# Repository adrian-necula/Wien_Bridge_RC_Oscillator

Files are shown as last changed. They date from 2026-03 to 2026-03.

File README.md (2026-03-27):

# Wien Bridge RC Oscillator

This repository contains the complete hardware design, TINA-TI simulation, and PCB layout for a tunable Wien Bridge RC Oscillator. The project was developed for the **Fundamental Electronic Circuits 2 (CEF2)** course at ETTI, UNSTPB.

## ⚙️ Technical Specifications
The circuit generates a stable sine wave and features automatic amplitude control using a diode dipole. 
* **Tunable Frequency Range:** 9.5 kHz to 57 kHz.
* **Output Amplitude:** 0.70 V.
* **Output Load:** 19 kΩ.
* **Operating Temperature:** -40°C to 120°C.
* **Amplitude Control:** Automatic, implemented via a diode dipole network.
* **Visual Indicator:** LED power presence indicator.

## 🛠️ Tools & Technologies
* **Simulation:** TINA-TI (Transient and AC Analysis).
* **Schematic Capture:** OrCAD Capture CIS.
* **PCB Design:** OrCAD PCB Editor (Surface-Mount Technology - SMT).

## 📂 Repository Structure
The repository is organized to follow the standard hardware design flow:

* 📁 **`Schematics/`**: Contains the OrCAD source schematic (`.dsn`), the TINA-TI simulation file, and high-resolution images of the final schematic.
* 📁 **`Layout/`**: Contains the OrCAD PCB layout file (`.brd`), the generated manufacturing files (Gerbers/NC Drill), and an image of the routed PCB.
* 📁 **`Simulations/`**: Contains oscilloscope screenshots from TINA-TI verifying the sine wave generation and frequency response.
* 📁 **`Data_Sheets/`**: Official manufacturer datasheets for the critical components used in the design (e.g., op-amps, diodes).
* 🖼️ **`schema_bloc.png`**: The system-level block diagram illustrating the oscillator's functional stages.
* 📄 **`BOM_P1_Necula_Adrian.xls`**: The Bill of Materials detailing the selected components.
* 📄 **`Documentatie.pdf`**: The comprehensive project report, including design equations, thermal considerations, and full layout prints.

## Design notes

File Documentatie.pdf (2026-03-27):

## UNIVERSITATEA NAȚIONALĂ de ȘTIINȚĂ și

## TEHNOLOGIE POLITEHNICA din BUCUREŞTI

## Facultatea de Electronică, Telecomunicaţii şi Tehnologia Informaţiei

## Circuite electronice fundamentale 2 - Proiect

Student: | Necula Adrian-Nicușor
Coordonatori: | Conf. Dr. Ing. Florin Drăghici Ș.l. Dr. Ing. Mihaela Pantazică

### Grupa 433E

### București 2025 – 2026

### 1. Date inițiale de proiectare

- N = 19;
- Frecvența de oscilaţie reglabilă, fosc în intervalul [0,5N ; 3N] kHz, adică [9,5 ; 57] kHz;
- Sarcina la ieșire N, adică RL = 19 kΩ;
- Control automat al amplitudinii de oscilaţie realizat cu dipol cu diode;
- Amplitudinea oscilației la ieșire [20/1,5N] V, adică vosc = 0,70 V;
- Domeniul temperaturilor de funcționare: [-40 ; 120] °C (verificabil prin testare în temperatură);
- Semnalizarea prezenței tensiunilor de alimentare cu diodă de tip LED.

Circuitul va fi proiectat și realizat sub forma unui modul electronic a cărui structură de interconectare va fi concepută în: Tehnologie SMT & PCB.

### 2. Schema bloc a circuitului

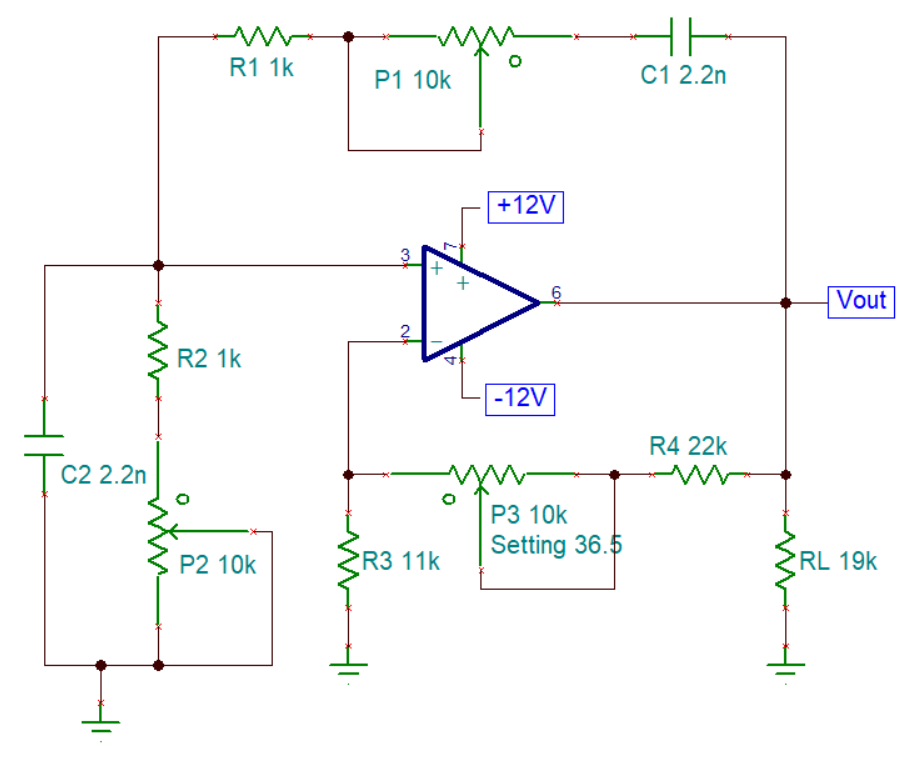
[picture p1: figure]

C1 = C2 = 2.2 nF
R1 =R2 = 1 kΩ
P1 = P2 = [0 ; 10] kΩ

fosc =

1
2πRC

= [9,5 ; 57] kHz

Se pot identifica următoarele blocuri componente:

- Amplificatorul de bază;
- Rețeaua Wien (R1 + P1 = R2 + P2, C1 = C2); Pentru Rețeaua Wien frecvența de oscilație fosc =

1
2πRC

. Valorile pentru componente au fost alese astfel încât să fie acoperită gama de frecvențe indicată indiferent de toleranțele acestora. P1, respectiv P2 sunt potențiometre duble ce permit reglajul simultan al brațelor punții Wien și pentru a avea fosc,min setăm potențiometrele la 66.15 %, iar pentru fosc,max la 2.69 %.
- Rețeaua de reacție negativă formată din R3 și P3 + R4;
- Rezistența de sarcină RL.

### 3. Proiectarea amplificatorului

Următoarea figură prezintă schema finală de implementare a amplificatorului. Acest circuit conține amplificatorul de bază și rețeaua de reacție negativă.

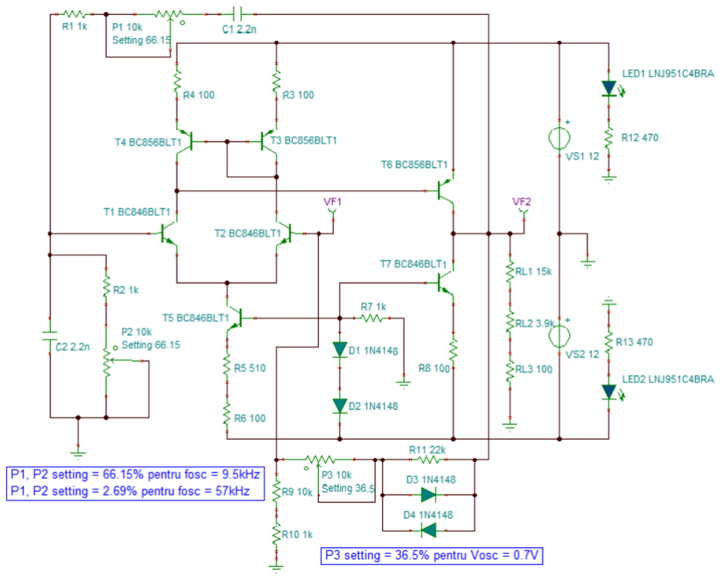
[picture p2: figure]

Amplificatorul este format din următoarele blocuri componente:

1. Etajul diferențial de intrare este realizat de tranzistoarele T1 și T2, ce are rolul de a amplifica diferența de tensiune dintre intrări;
2. Oglinda de curent formată din T3 și T4 are rolul de a menţine un curent egal pe ramurile diferenţialului, cu ajutorul rezistorilor R3 = R4 = 100 Ω;
3. Tranzistoarele T5 și T7, împreună cu diodele D1, D2 și rezistorul R7, formează o sursă de curent constant (Itail) la ieșirea din etajul diferențial;
4. Tranzistorul T6, formează ieșirea oscilatorului, acesta situându-se în clasa A de funcționare.

Rețeaua de reacție negativă, formată din R9, R10, P3 + R11 și diodele D3, respectiv D4, este de topologie Serie-Paralel, pentru a obține Rin → ∞, Rout → 0 și o amplificare de A = 3, specifică Oscilatorului RC cu punte Wien. Potențiometrul P3 are rolul de a regla valoarea amplitudinii la ieșire vosc, iar dipolul cu diode o va stabiliza, astfel asigurând reglajul automat al amplitudinii de oscilație.

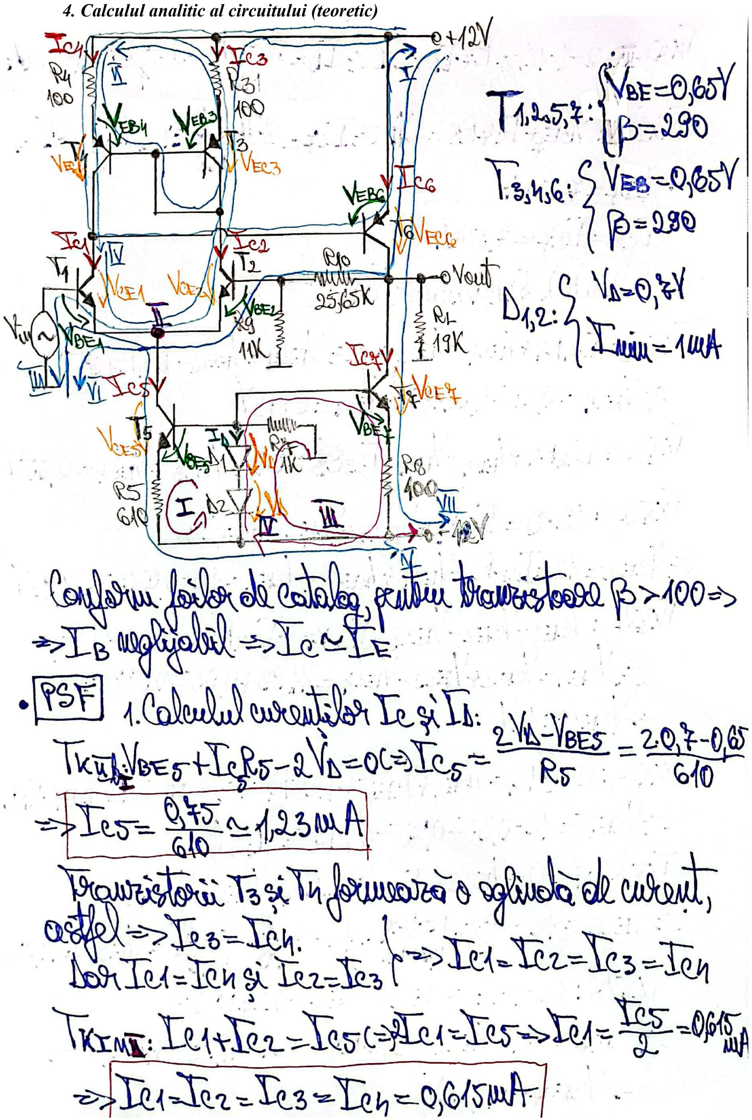
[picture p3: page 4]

### 4. Calculul analitic al circuitului (teoretic)

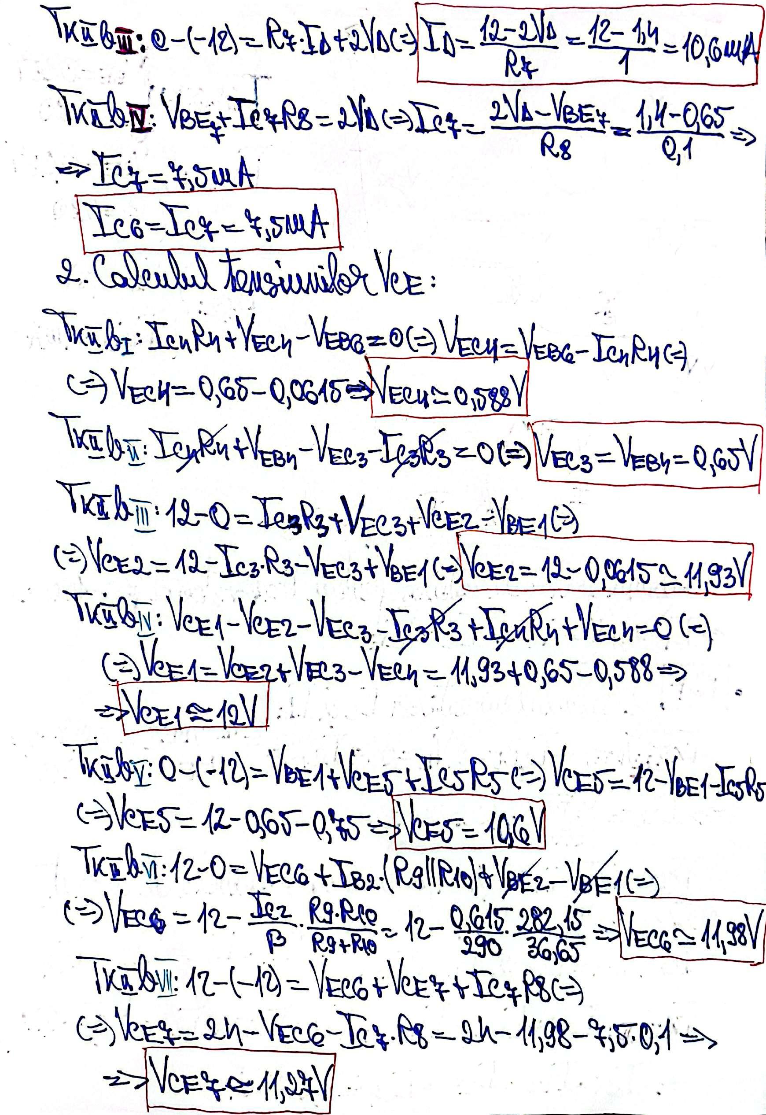
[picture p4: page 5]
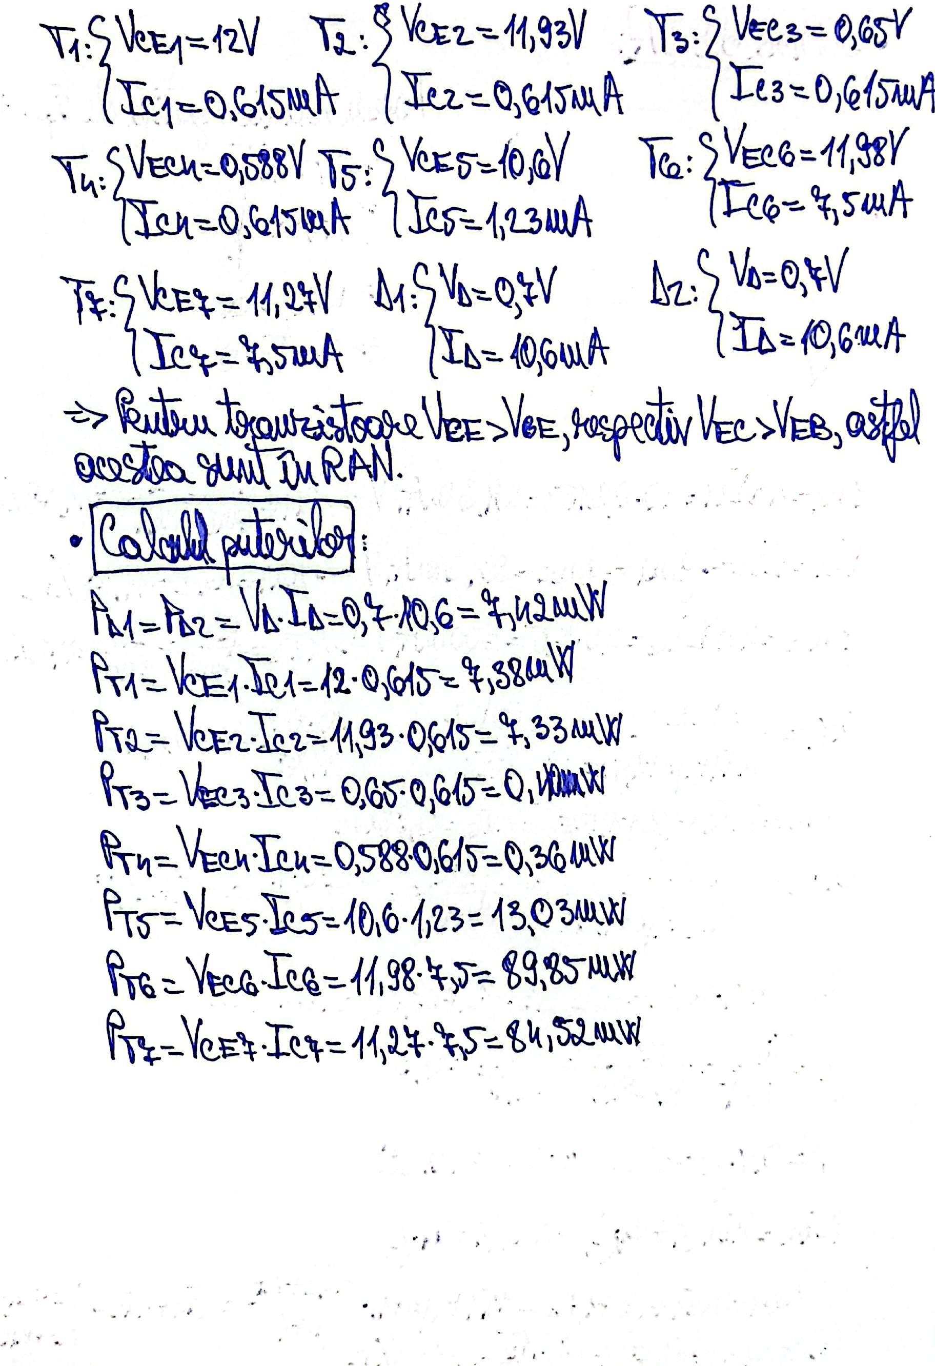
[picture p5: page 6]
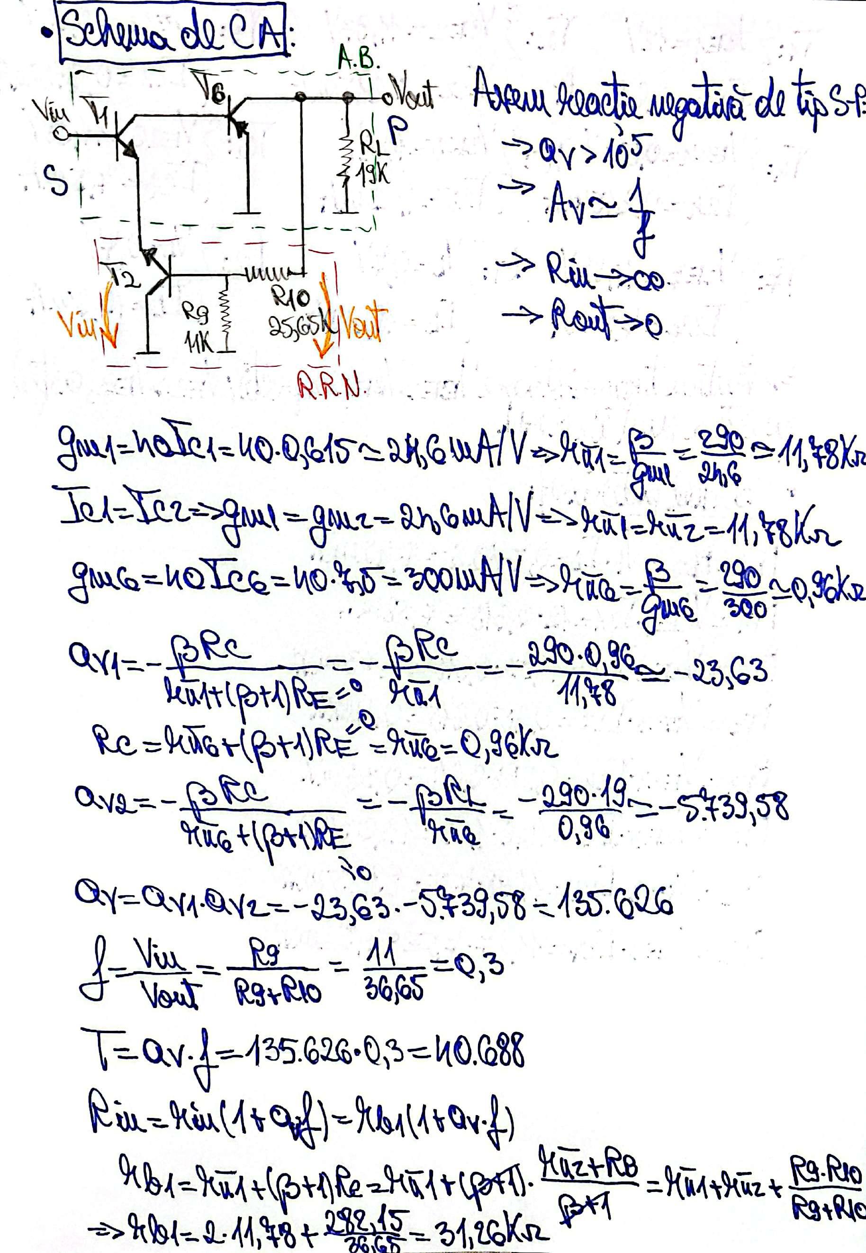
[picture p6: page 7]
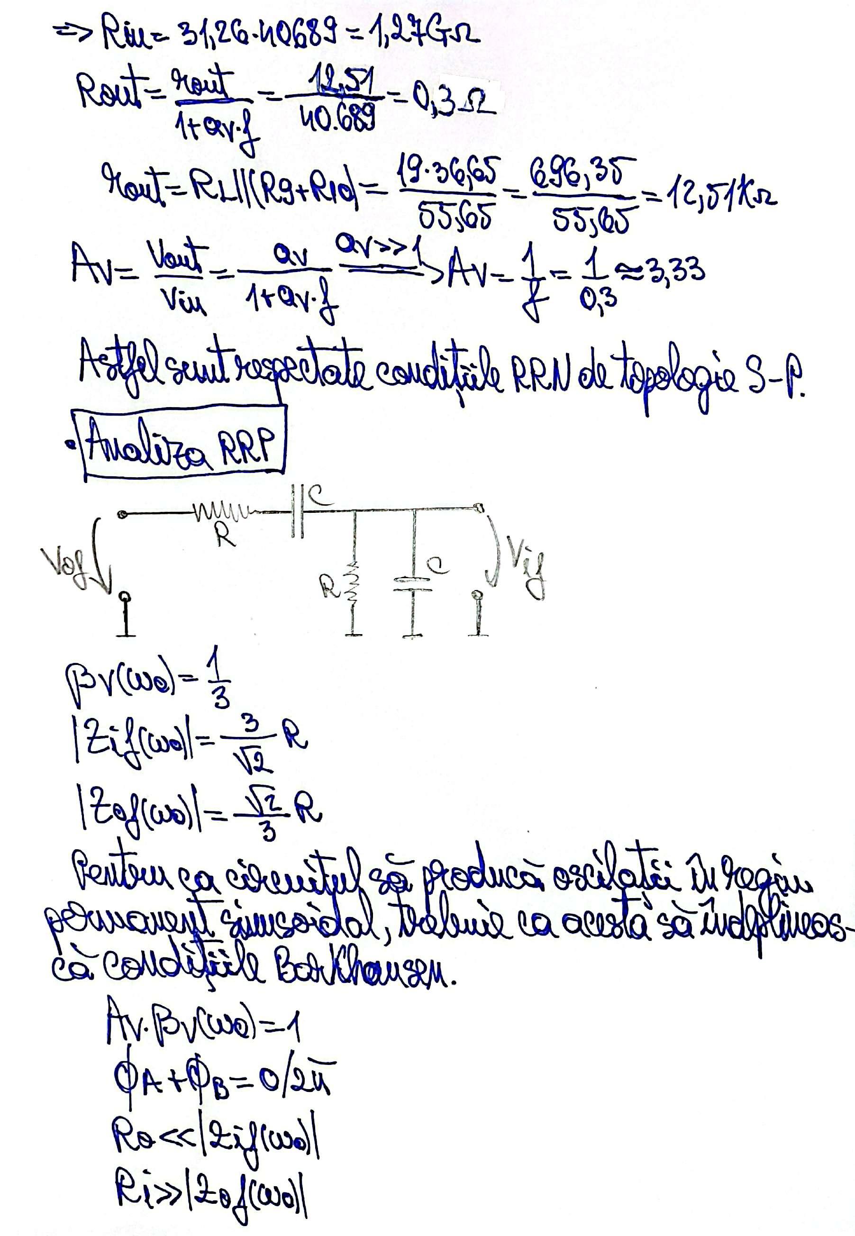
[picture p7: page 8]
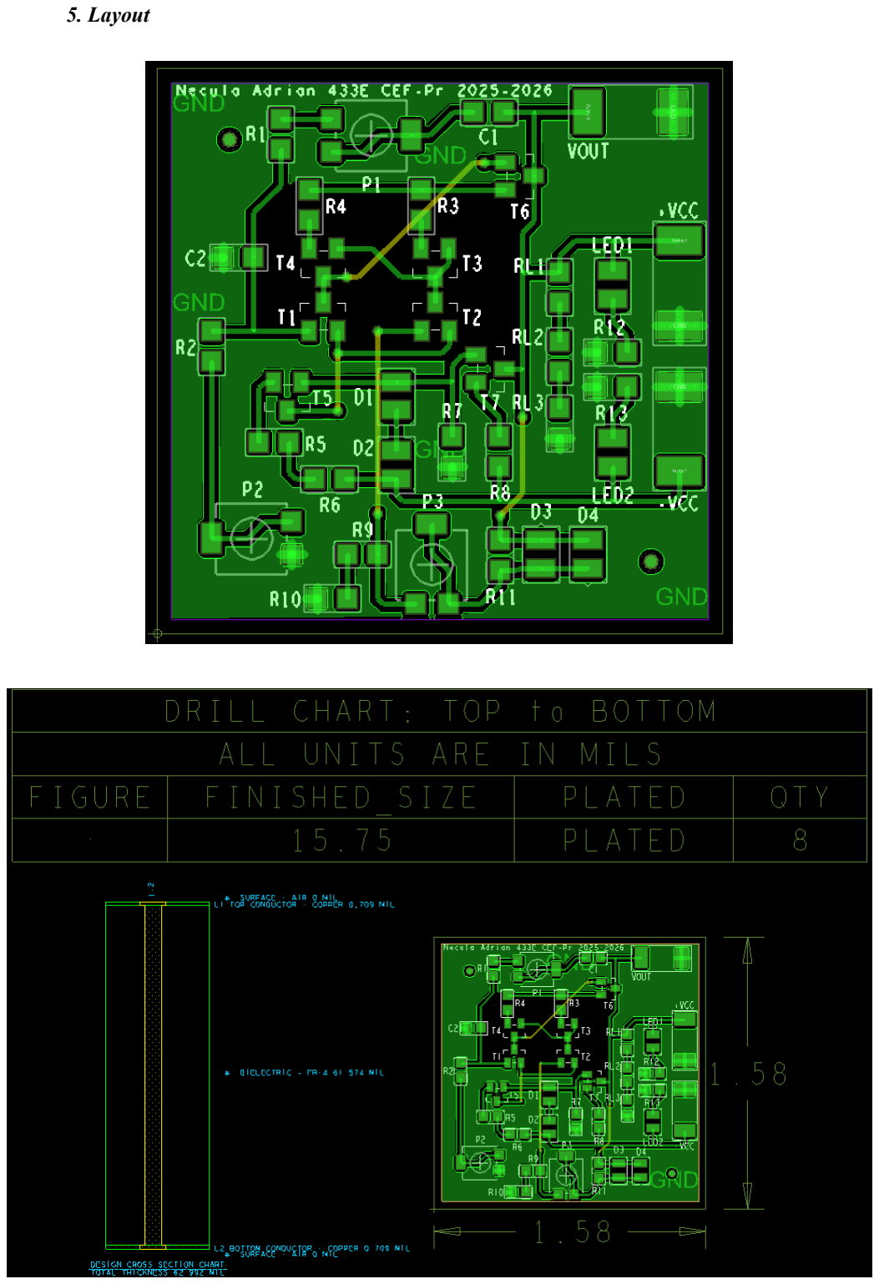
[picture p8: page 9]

### 5. Layout

- Layer electric: TOP

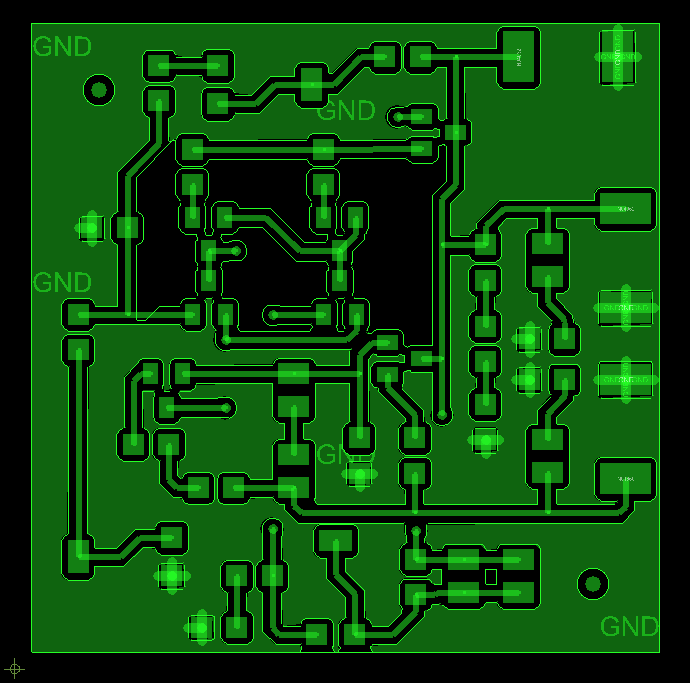
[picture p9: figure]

- Layer electric: BOTTOM

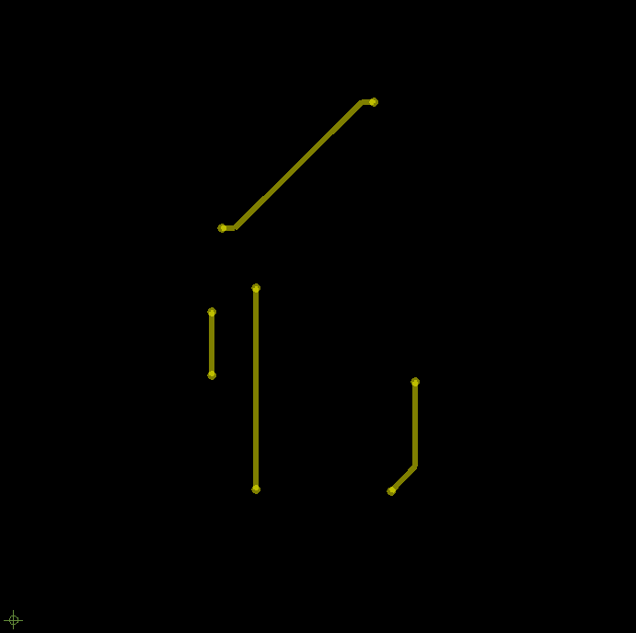
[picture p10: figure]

- Layer neelectric: SMTOP (Solder Mask Top)

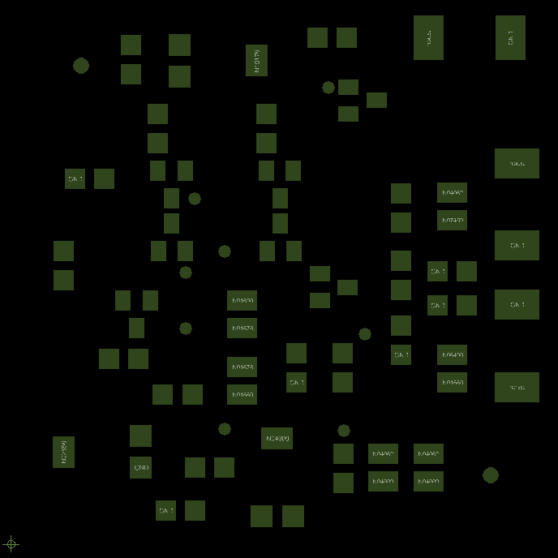
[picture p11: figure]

- Layer neelectric: SMBOT (Solder Mask Bottom)

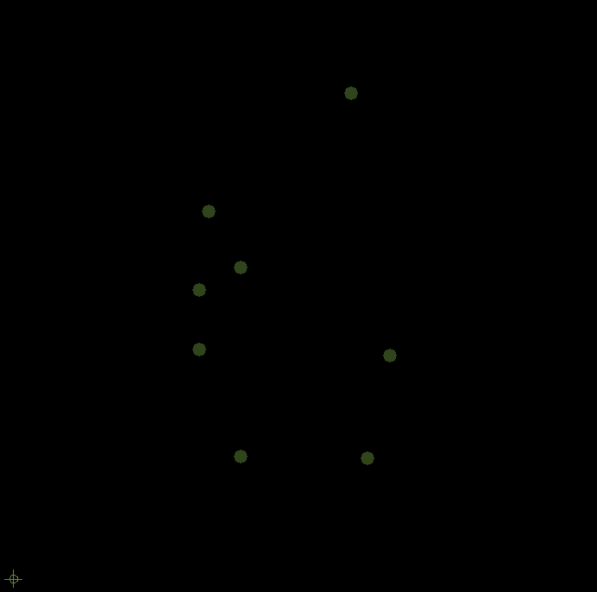
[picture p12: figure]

- Layer neelectric: SSTOP (Silk Screen Top)

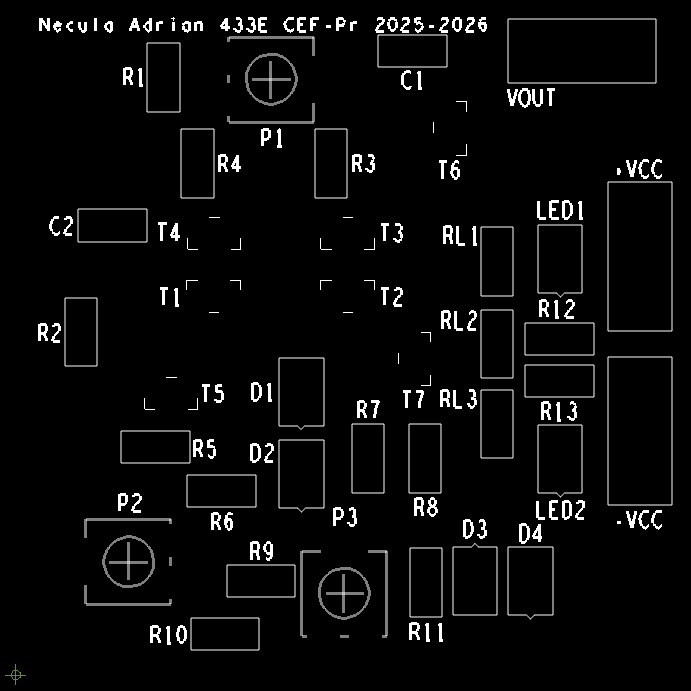
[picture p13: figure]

- Layer neelectric: SPTOP (Solder Paste/Paste Mask Top)

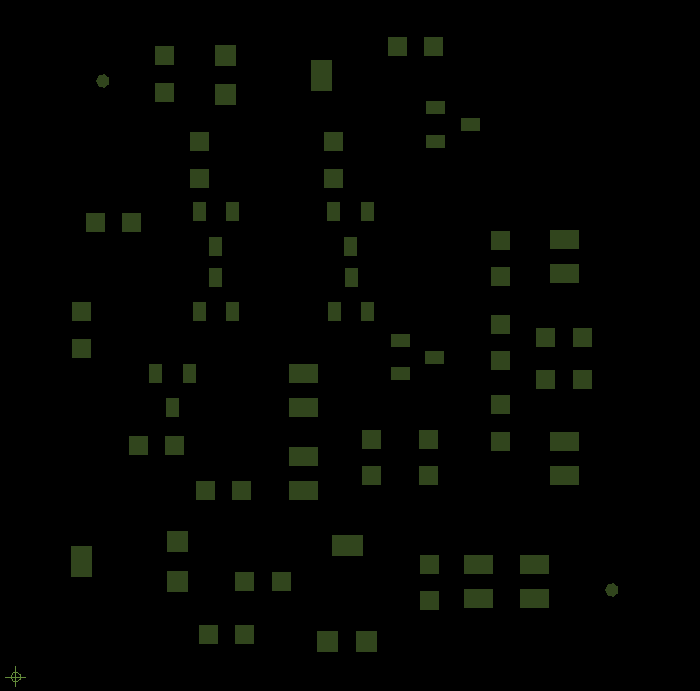
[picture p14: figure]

- Layer neelectric: FAB (Fabrication/Mecanic)

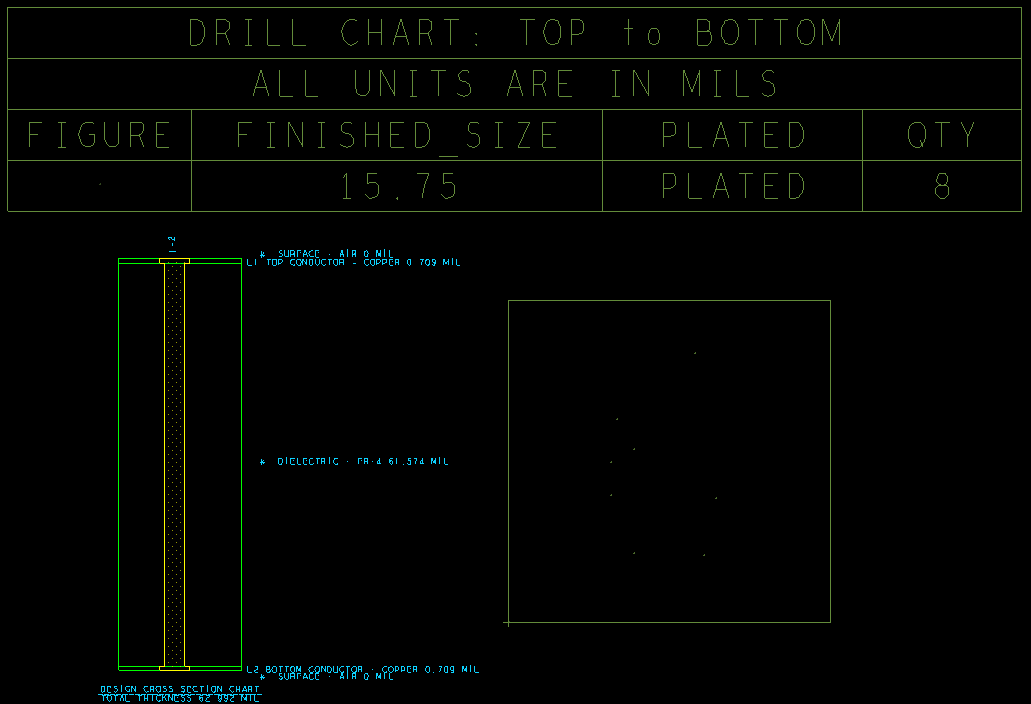
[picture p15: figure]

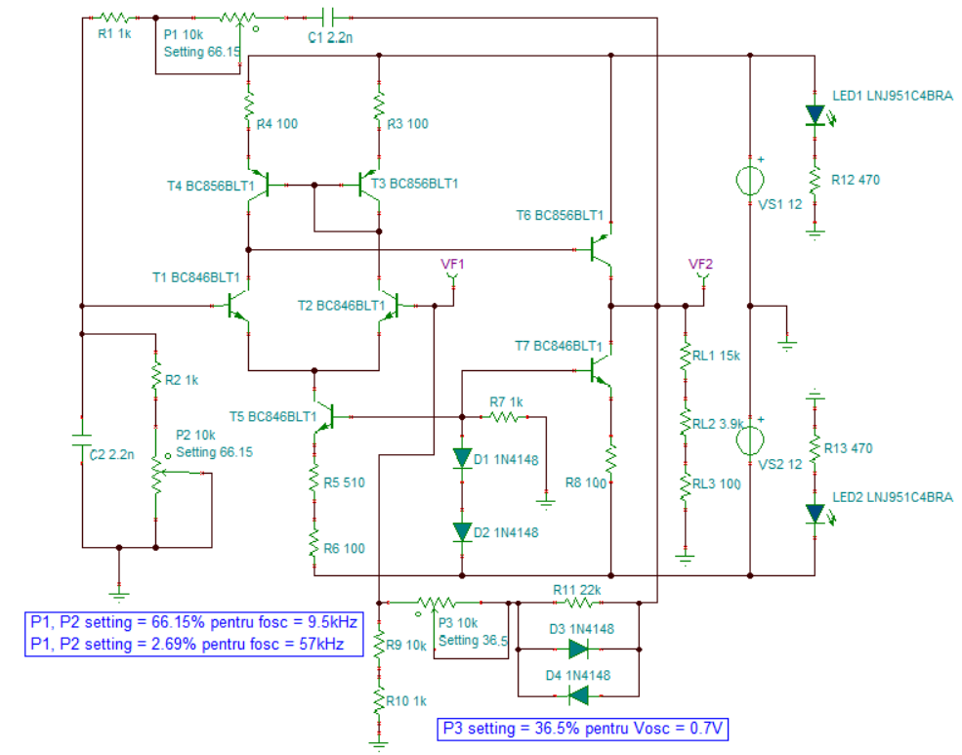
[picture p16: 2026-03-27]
Schematics/schema_finala.png

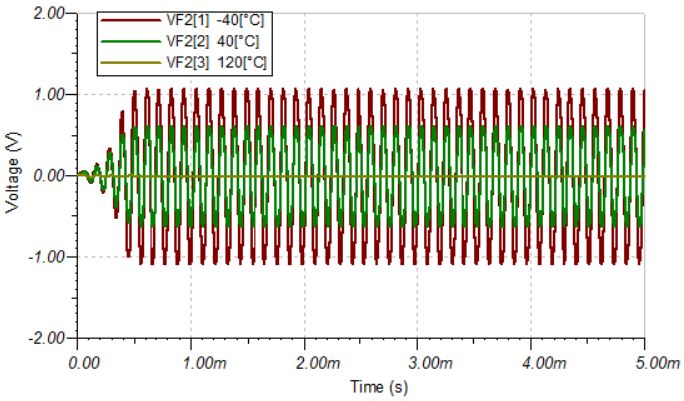
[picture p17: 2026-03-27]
Simulations/variatie_temp_fmin.png

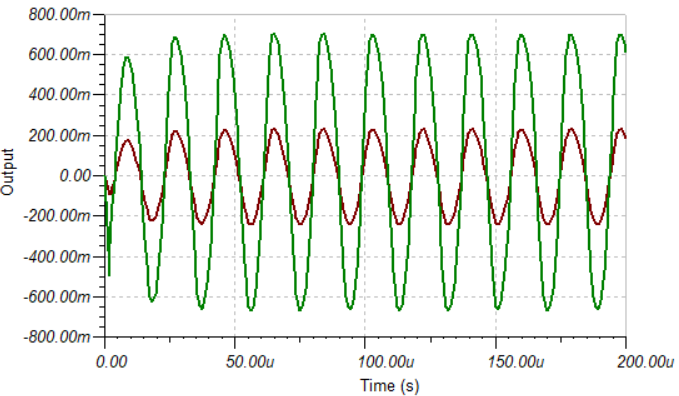
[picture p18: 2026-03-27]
Simulations/fmax.png

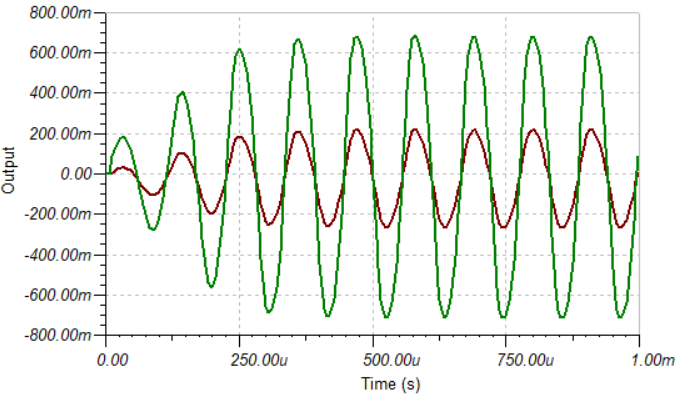
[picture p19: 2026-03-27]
Simulations/fmin.png

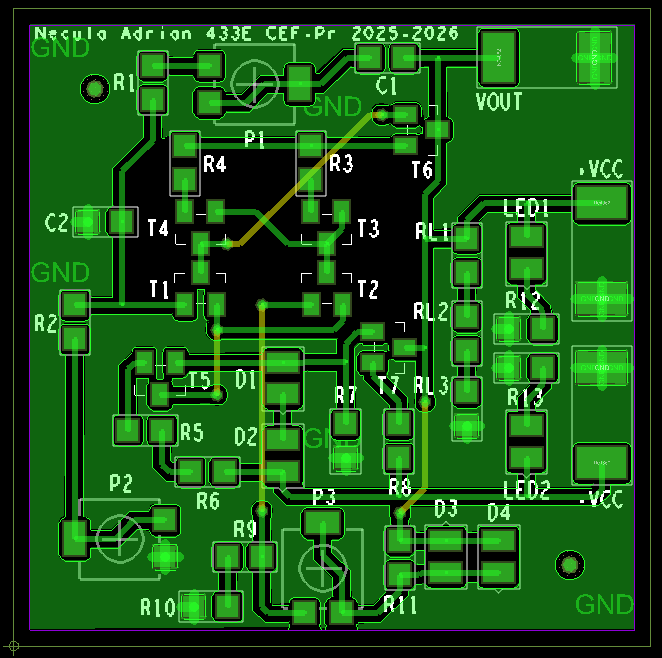
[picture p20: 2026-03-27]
Layout/layout.png

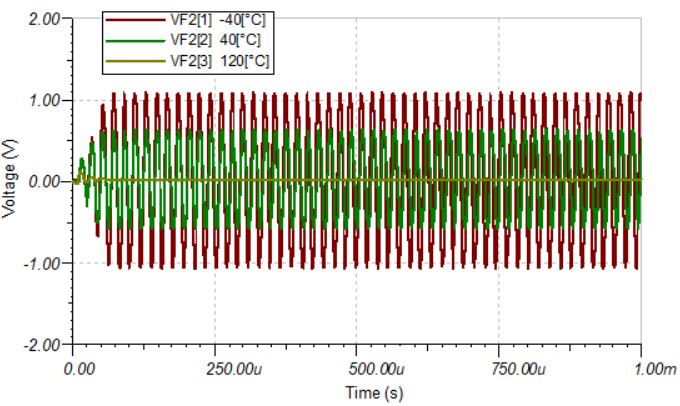
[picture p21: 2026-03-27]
Simulations/variatie_temp_fmax.png

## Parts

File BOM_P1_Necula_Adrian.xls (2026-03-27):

Anexa a1 - Grupa 433E - Tema 1- Oscilator RC cu retea Wien
Nr. Crt. | Nume | Catalog | Cod distrib | Nume prod | Prod | Clasă | Qty fix | Qty final | Qty min | Descriere | Distribuitor | Pret (fara TVA) referinta/buc. TME România | Pret total pe reper (fara TVA) - propus
1 | 0 ohm | (LINK) (http://www.tme.eu/ro/details/smd1206-0r/rezistente-smd-1206/royal-ohm/1206s4j0000t5e/) | 1206S4J0000T5E | 1206S4J0000T5E | SR PASSIVES | rezistor | 0 |  | 0 | Rezistor: thick film; SMD; 1206; 0Ω; 0,25W; ±5%; -55÷125°C | TME România | 0.03841 | 0
2 | 0.47 | (LINK) (http://www.tme.eu/ro/details/smd0805-0r47/rezistente-smd-0805/royal-ohm/0805s8j047kt5e/) | SMD0805-0R47 | 0805S8J047KT5E | ROYAL OHM | rezistor | 20 |  | 0 | Rezistor SMD, chip, 0805, 0.47Ω, ±5%, 0.125W | TME România | 0.01454 | 0.2908
3 | 1 | (LINK) (https://www.tme.eu/ro/details/smd0805-1r/rezistente-smd-0805/royal-ohm/0805s8j010jt5e/) | SMD0805-1R-5% | 0805S8J010JT5E | ROYAL OHM | rezistor | 20 |  | 0 | Rezistor SMD, chip, 0805, 1Ω, ±5%, 0.125W | TME România | 0.01723 | 0.3446
4 | 4.7 | (LINK) (https://www.tme.eu/ro/details/smd0805-4r7/rezistente-smd-0805/royal-ohm/0805s8j047jt5e/) | SMD0805-4R7-5% | 0805S8J047JT5E | ROYAL OHM | rezistor | 10 |  | 0 | Rezistor SMD, chip, 0805, 4.7Ω, ±5%, 0.125W | TME România | 0.01723 | 0.1723
5 | 10 | (LINK) (https://www.tme.eu/ro/details/smd0805-10r/rezistente-smd-0805/royal-ohm/0805s8j0100t5e/) | SMD0805-10R-5% | 0805S8J0100T5E | ROYAL OHM | rezistor | 10 |  | 0 | Rezistor SMD, chip, 0805, 10Ω, ±5%, 0.125W | TME România | 0.01723 | 0.1723
6 | 22 | (LINK) (https://www.tme.eu/ro/details/smd0805-22r-1%25/rezistente-smd-0805/royal-ohm/0805s8f220jt5e/) | SMD0805-22R-1% | 0805S8F220JT5E | ROYAL OHM | rezistor | 20 |  | 0 | Rezistor SMD, chip, 0805, 22Ω, ±1%, 0.125W | TME România | 0.02127 | 0.4254
7 | 33 | (LINK) (https://www.tme.eu/ro/details/smd0805-33r/rezistente-smd-0805/royal-ohm/0805s8j0330t5e/) | SMD0805-33R-5% | 0805S8J0330T5E | ROYAL OHM | rezistor | 20 |  | 0 | Rezistor SMD, chip, 0805, 33Ω, ±5%, 0.125W | TME România | 0.01723 | 0.3446
8 | 51 | (LINK) (http://www.tme.eu/ro/details/rc0805jr-0751r/rezistente-smd-0805/yageo/rc0805jr-0751rl/) | SMD0805-51R-5% | 0805S8J0510T5E | ROYAL OHM | rezistor | 40 |  | 0 | Rezistor SMD, chip, 0805, 51Ω, ±5%, 0.125W | TME România | 0.0261 | 1.044
9 | 68 | (LINK) (http://www.tme.eu/ro/details/smd0805-68r-1%25/rezistente-smd-0805/royal-ohm/0805s8f680jt5e/) | SMD0805-68R-1% | 0805S8F680JT5E | ROYAL OHM | rezistor | 10 |  | 0 | Rezistor SMD, chip, 0805, 68Ω, ±1%, 0.125W | TME România | 0.04662 | 0.4662
10 | 82 | (LINK) (https://www.tme.eu/ro/details/wf08p-82r-5%25/rezistente-smd-0805/walsin/wf08p820jtl/) | SMD0805-82R-5% | WF08P820JTL | WALSIN | rezistor | 20 |  | 0 | Rezistor SMD, chip, 0805, 82Ω, ±5%, 0.125W | TME România | 0.0172 | 0.344
11 | 100 | (LINK) (https://www.tme.eu/ro/details/smd0805-100r/rezistente-smd-0805/royal-ohm/0805s8j0101t5e/) | SMD0805-100R-5% | 0805S8J0101T5E | ROYAL OHM | rezistor | 60 |  | 5 | Rezistor SMD, chip, 0805, 100Ω, ±5%, 0.125W | TME România | 0.01723 | 1.0338
12 | 150 | (LINK) (https://www.tme.eu/ro/details/smd0805-150r/rezistente-smd-0805/royal-ohm/0805s8j0151t5e/) | SMD0805-150R-5% | 0805S8F1500T5E | ROYAL OHM | rezistor | 30 |  | 0 | Rezistor SMD, chip, 0805, 150Ω, ±5%, 0.125W | TME România | 0.01723 | 0.5169
13 | 220 | (LINK) (http://www.tme.eu/ro/details/smd0805-220r-1%25/rezistente-smd-0805/royal-ohm/0805s8f2200t5e/) | SMD0805-220R-5% | 0805S8J0221T5E | ROYAL OHM | rezistor | 30 |  | 0 | Rezistor SMD, chip, 0805, 220Ω, ±5%, 0.125W | TME România | 0.02127 | 0.6381
14 | 330 | (LINK) (https://www.tme.eu/ro/details/smd0805-330r/rezistente-smd-0805/royal-ohm/0805s8j0331t5e/) | SMD0805-330R-5% | 0805S8J0331T5E | ROYAL OHM | rezistor | 30 |  | 0 | Rezistor SMD, chip, 0805, 330Ω, ±5%, 0.125W | TME România | 0.01723 | 0.5169
15 | 470 | (LINK) (https://www.tme.eu/ro/details/smd0805-470r/rezistente-smd-0805/royal-ohm/0805s8j0471t5e/) | SMD0805-470R-5% | 0805S8J0471T5E | ROYAL OHM | rezistor | 30 |  | 2 | Rezistor SMD, chip, 0805, 470Ω, ±5%, 0.125W | TME România | 0.01723 | 0.5169
16 | 510 | (LINK) (https://www.tme.eu/ro/details/smd0805-510r/rezistente-smd-0805/royal-ohm/0805s8j0511t5e/) | SMD0805-510R-5% | 0805S8J0511T5E | ROYAL OHM | rezistor | 30 |  | 1 | Rezistor SMD, chip, 0805, 510Ω, ±5%, 0.125W | TME România | 0.01723 | 0.5169
17 | 680 | (LINK) (https://www.tme.eu/ro/details/smd0805-680r/rezistente-smd-0805/royal-ohm/0805s8j0681t5e/) | SMD0805-680R-5% | 0805S8J0681T5E | ROYAL OHM | rezistor | 30 |  | 0 | Rezistor SMD, chip, 0805, 680Ω, ±5%, 0.125W | TME România | 0.01723 | 0.5169
18 | 820 | (LINK) (https://www.tme.eu/ro/details/smd0805-820r/rezistente-smd-0805/royal-ohm/0805s8j0821t5e/) | SMD0805-820R-5% | 0805S8J0821T5E | ROYAL OHM | rezistor | 30 |  | 0 | Rezistor SMD, chip, 0805, 820Ω, ±5%, 0.125W | TME România | 0.01723 | 0.5169
19 | 910 | (LINK) (https://www.tme.eu/ro/details/rc0805jr-07910r/rezistente-smd-0805/yageo/rc0805jr-07910rl/) | SMD0805-910R-5% | RC0805JR-07910RL | YAGEO | rezistor | 40 |  | 0 | Rezistor SMD, chip, 0805, 910Ω, ±5%, 0.125W | TME România | 0.0261 | 1.044
20 | 1k | (LINK) (https://www.tme.eu/ro/details/smd0805-1k/rezistente-smd-0805/royal-ohm/0805s8j0102t5e/) | SMD0805-1K-5% | 0805S8J0102T5E | ROYAL OHM | rezistor | 100 |  | 4 | Rezistor SMD, chip, 0805, 1kΩ, ±5%, 0.125W | TME România | 0.01723 | 1.723
21 | 1.5k | (LINK) (https://www.tme.eu/ro/details/wf08p-1k5-5%25/rezistente-smd-0805/walsin/wf08p152jtl/) | SMD0805-1K5-5% | WF08P152JTL | WALSIN | rezistor | 40 |  | 0 | Rezistor SMD, chip, 0805, 1.5kΩ, ±5%, 0.125W | TME România | 0.0172 | 0.688
22 | 1.8k | (LINK) (https://www.tme.eu/ro/details/smd0805-1k8/rezistente-smd-0805/royal-ohm/0805s8j0182t5e/) | SMD0805-1K8-5% | 0805S8J0182T5E | ROYAL OHM | rezistor | 30 |  | 0 | Rezistor SMD, chip, 0805, 1.8kΩ, ±5%, 0.125W | TME România | 0.01723 | 0.5169
23 | 2k | (LINK) (https://www.tme.eu/ro/details/smd0805-2k/rezistente-smd-0805/royal-ohm/0805s8j0202t5e/) | SMD0805-2K-5% | 0805S8J0202T5E | ROYAL OHM | rezistor | 80 |  | 0 | Rezistor SMD, chip, 0805, 2kΩ, ±5%, 0.125W | TME România | 0.01723 | 1.3784
24 | 2.2k | (LINK) (https://www.tme.eu/ro/details/smd0805-2k2/rezistente-smd-0805/royal-ohm/0805s8j0222t5e/) | SMD0805-2K2-5% | 0805S8J0222T5E | ROYAL OHM | rezistor | 30 |  | 0 | Rezistor SMD, chip, 0805, 2.2kΩ, ±5%, 0.125W | TME România | 0.01723 | 0.5169
25 | 2.7k | (LINK) (https://www.tme.eu/ro/details/smd0805-2k7/rezistente-smd-0805/royal-ohm/0805s8j0272t5e/) | SMD0805-2K7-5% | 0805S8F2701T5E | ROYAL OHM | rezistor | 30 |  | 0 | Rezistor SMD, chip, 0805, 2.7kΩ, ±5%, 0.125W | TME România | 0.01723 | 0.5169
26 | 3.3k | (LINK) (https://www.tme.eu/ro/details/smd0805-3k3/rezistente-smd-0805/royal-ohm/0805s8j0332t5e/) | SMD0805-3K3-5% | 0805S8J0332T5E | ROYAL OHM | rezistor | 30 |  | 0 | Rezistor SMD, chip, 0805, 3.3kΩ, ±5%, 0.125W | TME România | 0.01723 | 0.5169
27 | 3.9k | (LINK) (https://www.tme.eu/ro/details/smd0805-3k9/rezistente-smd-0805/royal-ohm/0805s8j0392t5e/) | SMD0805-3K9-5% | 0805S8J0392T5E | ROYAL OHM | rezistor | 20 |  | 1 | Rezistor SMD, chip, 0805, 3.9kΩ, ±5%, 0.125W | TME România | 0.01723 | 0.3446
28 | 4.7k | (LINK) (https://www.tme.eu/ro/details/smd0805-4k7/rezistente-smd-0805/royal-ohm/0805s8j0472t5e/) | SMD0805-4K7-5% | 0805S8J0472T5E | ROYAL OHM | rezistor | 30 |  | 0 | Rezistor SMD, chip, 0805, 4.7kΩ, ±5%, 0.125W | TME România | 0.01723 | 0.5169
29 | 5.6k | (LINK) (https://www.tme.eu/ro/details/smd0805-5k6/rezistente-smd-0805/royal-ohm/0805s8j0562t5e/) | SMD0805-5K6-5% | 0805S8J0562T5E | ROYAL OHM | rezistor | 60 |  | 0 | Rezistor SMD, chip, 0805, 5.6kΩ, ±5%, 0.125W | TME România | 0.01723 | 1.0338
30 | 6.8k | (LINK) (https://www.tme.eu/ro/details/rc0805jr-076k8/rezistente-smd-0805/yageo/rc0805jr-076k8l/) | SMD0805-6K8-5% | RC0805JR-076K8L | YAGEO | rezistor | 20 |  | 0 | Rezistor SMD, chip, 0805, 6.8kΩ, ±5%, 0.125W | TME România | 0.0261 | 0.522
31 | 8.2k | (LINK) (https://www.tme.eu/ro/details/smd0805-8k2/rezistente-smd/royalohm/0805s8j0822t5e/) | SMD0805-8K2-5% | 0805S8J0822T5E | ROYAL OHM | rezistor | 30 |  | 0 | Rezistor SMD, chip, 0805, 8.2kΩ, ±5%, 0.125W | TME România | 0.01723 | 0.5169
32 | 9.1k | (LINK) (https://www.tme.eu/ro/details/smd0805-9k1/rezistente-smd-0805/royal-ohm/0805s8j0912t5e/) | SMD0805-9K1-5% | 0805S8J0912T5E | ROYAL OHM | rezistor | 20 |  | 0 | Rezistor SMD, chip, 0805, 9.1kΩ, ±5%, 0.125W | TME România | 0.01723 | 0.3446
33 | 10k | (LINK) (https://www.tme.eu/ro/details/smd0805-10k/rezistente-smd-0805/royal-ohm/0805s8j0103t5e/) | SMD0805-10K-5% | 0805S8J0103T5E | ROYAL OHM | rezistor | 100 |  | 1 | Rezistor SMD, chip, 0805, 10kΩ, ±5%, 0.125W | TME România | 0.01723 | 1.723
34 | 15k | (LINK) (https://www.tme.eu/ro/details/smd0805-15k/rezistente-smd-0805/royal-ohm/0805s8j0153t5e/) | SMD0805-15K-5% | 0805S8J0153T5E | ROYAL OHM | rezistor | 30 |  | 1 | Rezistor SMD, chip, 0805, 15kΩ, ±5%, 0.125W | TME România | 0.01723 | 0.5169
35 | 22k | (LINK) (https://www.tme.eu/ro/details/smd0805-22k/rezistente-smd-0805/royal-ohm/0805s8j0223t5e/) | SMD0805-22K-5% | 0805S8J0223T5E | ROYAL OHM | rezistor | 30 |  | 1 | Rezistor SMD, chip, 0805, 22kΩ, ±5%, 0.125W | TME România | 0.01723 | 0.5169
36 | 47k | (LINK) (http://www.tme.eu/ro/details/smd0805-47k/rezistente-smd-0805/royal-ohm/0805s8j0473t5e/) | SMD0805-47K-5% | 0805S8J0473T5E | ROYAL OHM | rezistor | 40 |  | 0 | Rezistor: thick film; SMD; 0805; 47kΩ; 0,125W; ±5%; -55÷125°C | TME România | 0.01723 | 0.6892
37 | 68k | (LINK) (https://www.tme.eu/ro/details/smd0805-68k/rezistente-smd-0805/royal-ohm/0805s8j0683t5e/) | SMD0805-68K-5% | 0805S8J0683T5E | ROYAL OHM | rezistor | 20 |  | 0 | Rezistor SMD, chip, 0805, 68kΩ, ±5%, 0.125W | TME România | 0.01723 | 0.3446
38 | 100k | (LINK) (https://www.tme.eu/ro/details/smd0805-100k/rezistente-smd-0805/royal-ohm/0805s8j0104t5e/) | SMD0805-100K-5% | 0805S8J0104T5E | ROYAL OHM | rezistor | 100 |  | 0 | Rezistor SMD, chip, 0805, 100kΩ, ±5%, 0.125W | TME România | 0.01723 | 1.723
39 | 150k | (LINK) (http://www.tme.eu/ro/details/smd0805-150k/rezistente-smd-0805/royal-ohm/0805s8j0154t5e/) | SMD0805-150K-5% | 0805S8J0154T5E | ROYAL OHM | rezistor | 30 |  | 0 | Rezistor SMD, chip, 0805, 150kΩ, ±5%, 0.125W | TME România | 0.01723 | 0.5169
40 | 180k | (LINK) (http://www.tme.eu/ro/details/smd0805-180k/rezistente-smd-0805/royal-ohm/0805s8j0184t5e/) | SMD0805-180K-5% | 0805S8J0184T5E | ROYAL OHM | rezistor | 30 |  | 0 | Rezistor SMD, chip, 0805, 180kΩ, ±5%, 0.125W | TME România | 0.01723 | 0.5169
41 | 220k | (LINK) (https://www.tme.eu/ro/details/smd0805-220k/rezistente-smd-0805/royal-ohm/0805s8j0224t5e/) | SMD0805-220K-5% | 0805S8J0224T5E | ROYAL OHM | rezistor | 30 |  | 0 | Rezistor SMD, chip, 0805, 220kΩ, ±5%, 0.125W | TME România | 0.01723 | 0.5169
42 | 330k | (LINK) (https://www.tme.eu/ro/details/smd0805-330k/rezistente-smd-0805/royal-ohm/0805s8j0334t5e/) | SMD0805-330K-5% | 0805S8J0334T5E | ROYAL OHM | rezistor | 30 |  | 0 | Rezistor SMD, chip, 0805, 330kΩ, ±5%, 0.125W | TME România | 0.01723 | 0.5169
43 | 390k | (LINK) (https://www.tme.eu/ro/details/smd0805-390k/rezistente-smd-0805/royal-ohm/0805s8j0394t5e/) | SMD0805-390K-5% | 0805S8J0394T5E | ROYAL OHM | rezistor | 30 |  | 0 | Rezistor SMD, chip, 0805, 390kΩ, ±5%, 0.125W | TME România | 0.01723 | 0.5169
44 | 510k | (LINK) (https://www.tme.eu/ro/details/smd0805-510k/rezistente-smd-0805/royal-ohm/0805s8j0514t5e/) | SMD0805-510K-5% | 0805S8J0514T5E | ROYAL OHM | rezistor | 30 |  | 0 | Rezistor SMD, chip, 0805, 510kΩ, ±5%, 0.125W | TME România | 0.01723 | 0.5169
45 | 1M | (LINK) (https://www.tme.eu/ro/details/crcw08051m00jntabc/rezistente-smd-0805/vishay/) | SMD0805-1M-5% | CRCW08051M00JNTABC | VISHAY | rezistor | 30 |  | 0 | Rezistor SMD, chip, 0805, 1MΩ, ±5%, 0.125W | TME România | 0.01151 | 0.3453
46 | 2M | (LINK) (http://www.tme.eu/ro/details/smd0805-2m/rezistente-smd-0805/royal-ohm/0805waj-2m-t5e/) | SMD0805-2M7 5% | 0805WAJ 2M T5E | ROYAL OHM | rezistor | 30 |  | 0 | Rezistor SMD, chip, 0805, 2MΩ, ±1%, 0.125W | TME România | 0.01723 | 0.5169
47 | 5,1M | (LINK) (http://www.tme.eu/ro/details/smd0805-5m1/rezistente-smd-0805/royal-ohm/0805s8j0515t5e/) | SMD0805-5M1 5% | RC0805FR-075M1 | Yageo | rezistor | 30 |  | 0 | Rezistor SMD, chip, 0805, 5.1MΩ, ±1%, 0.125W | TME România | 0.01723 | 0.5169
48 | 10M | (LINK) (https://www.tme.eu/ro/details/0805s8j0106t5e/rezistente-smd-0805/royal-ohm/) | SMD0805-10M 5% | 0805S8J0106T5E | ROYAL OHM | rezistor | 40 |  | 0 | Rezistor SMD, chip, 0805, 10MΩ, ±5%, 0.125W | TME România | 0.01723 | 0.6892
49 | 100ohm | (LINK) (https://www.tme.eu/ro/details/ts53yl100r/trimere-smd-cu-o-singura-tura/vishay/ts53yl101mr10/) | 1804GSMD-100R | 1804GSMD-100R | SR PASSIVES | potențiometru | 15 |  | 0 | Potențiome-tru liniar, simplă tură, SMD, 100Ω, ±10%, 100ppm/°C, 0.25W | TME România | 3.77 | 56.55
50 | 500ohm | (LINK) (https://www.tme.eu/ro/details/ts53yl500r/trimere-smd-cu-o-singura-tura/vishay/ts53yl501mr10/) | 1804GSMD-500R | 1804GSMD-500R | VISHAY | potențiometru | 0 |  | 0 | Potențiome-tru liniar, simplă tură, SMD, 500Ω, ±10%, 100ppm/°C, 0.25W | TME România | 2.19 | 0
51 | 2k | (LINK) (https://www.tme.eu/ro/details/ts53yl2k/trimere-smd-cu-o-singura-tura/vishay/ts53yl202mr10/) | TS53YL202MR10 | TS53YL202MR10 | VISHAY | potențiometru | 0 |  | 0 | Potențiome-tru liniar, simplă tură, SMD, 2kΩ, ±20%, 100ppm/°C, 0.25W | TME România | 2.84 | 0
52 | 5k | (LINK) (http://www.tme.eu/ro/details/3314g-1-502e/trimere-smd-cu-o-singura-tura/bourns/) | 3314G-1-502E | 3314G-1-502E | BOURNS | potențiometru | 0 |  | 0 | Potențiome-tru liniar, simplă tură, SMD, 5kΩ, ±20%, 100ppm/°C, 0.25W | TME România | 3.45 | 0
53 | 10k | (LINK) (http://www.tme.eu/ro/details/3314g-1-103e/trimere-smd-cu-o-singura-tura/bourns/) | 3314G-1-103E | 3314G-1-103E | BOURNS | potențiometru | 30 |  | 3 | Potențiome-tru liniar, simplă tură, SMD, 10kΩ, ±20%, 100ppm/°C, 0.25W | TME România | 3.0573 | 91.719
54 | 50k | (LINK) (http://www.tme.eu/ro/details/3314g-1-503e/trimere-smd-cu-o-singura-tura/bourns/) | 3314G-1-503E | 3314G-1-503E | BOURNS | potențiometru | 0 |  | 0 | Potențiome-tru liniar, simplă tură, SMD, 50kΩ, ±20%, 100ppm/°C, 0.25W | TME România | 2.84 | 0
55 | 100k | (LINK) (http://www.tme.eu/ro/details/ts53yl100k/trimere-smd-cu-o-singura-tura/vishay/ts53yl104mr10/) | TS53YL104MR10 | TS53YL104MR10 | VISHAY | potențiometru | 32 |  | 0 | Potențiome-tru liniar, simplă tură, SMD, 100kΩ, ±20%, 100ppm/°C, 0.25W | TME România | 2.61 | 83.52
56 | 500k | (LINK) (http://www.tme.eu/ro/details/3314g-1-504e/trimere-smd-cu-o-singura-tura/bourns/) | 3314G-1-504E | 3314G-1-504E | BOURNS | potențiometru | 10 |  | 0 | Potențiome-tru liniar, simplă tură, SMD, 500kΩ, ±10%, 100ppm/°C, 0.25W | TME România | 2.8802 | 28.802
 | TOTAL - Componente pasive (rezistoare de valori fixe şi reglabile) |  |  |  |  |  |  |  |  | FARA TVA = | 289.8316 | CU TVA= | 359.391184
57 | 4.7pF | (LINK) (http://www.tme.eu/ro/details/cc0805crnpo94r7/condensatoare-mlcc-smd-0805/yageo/cc0805crnpo9bn4r7/) | CC0805CRNPO9BN4R7 | CC0805CRNPO9BN4R7 | YAGEO | condensator | 20 |  | 0 | ceramic; MLCC; 4,7pF; 50V; C0G; ±0,25pF; SMD; 0805 | TME România | 0.16643 | 3.3286
58 | 10pF | (LINK) (http://www.tme.eu/ro/details/cc0805jrnpo9100/condensatoare-mlcc-smd-0805/yageo/cc0805jrnpo9bn100/) | CC0805JRNPO9BN100 | CC0805JRNPO9BN100 | YAGEO | condensator | 20 |  | 0 | ceramic; MLCC; 10pF; 50V; C0G; ±5%; SMD; 0805 | TME România | 0.1649 | 3.298
59 | 47pF | (LINK) (http://www.tme.eu/ro/details/cl21c470jbannnc/condensatoare-mlcc-smd-0805/samsung/) | CL21C470JBANNNC | CL21C470JBANNNC | SAMSUNG | condensator | 20 |  | 0 | Condensator: ceramic; MLCC; 47pF; 50V; C0G; ±5%; SMD; 0805; -55÷125°C | TME România | 0.11097 | 2.2194
60 | 100pF | (LINK) (http://www.tme.eu/ro/details/cl21c101jbannnc/condensatoare-mlcc-smd-0805/samsung/) | CL21C101JBANNNC | CL21C101JBANNNC | SAMSUNG | condensator | 20 |  | 0 | Condensator: ceramic; MLCC; 100pF; 50V; C0G; ±5%; SMD; 0805 | TME România | 0.05427 | 1.0854
61 | 470pF | (LINK) (https://www.tme.eu/ro/details/c0805c471k5rac/condensatoare-mlcc-smd/kemet/c0805c471k5ractu/) | C0805C471K5RACTU | C0805C471K5RACTU | KEMET | condensator | 20 |  | 0 | Condensator: ceramic; MLCC; 470pF; 50V; X7R; ±10%; SMD; 0805 | TME România | 0.12123 | 2.4246
62 | 1nF | (LINK) (https://www.tme.eu/ro/details/cl21b102kbannnc/condensatoare-mlcc-smd/samsung/) | CL21B102KBANNNC | CL21B102KBANNNC | SAMSUNG | condensator | 40 |  | 0 | Condensator MLCC, SMD, 0805, 1nF, ±5%, 50V, C0G | TME România | 0.06487 | 2.5948
63 | 2.2nF | (LINK) (https://www.tme.eu/ro/details/cl21b222jbannnc/condensatoare-mlcc-smd-0805/samsung/) | CL21B222JBANNNC | CL21B222JBANNNC | SAMSUNG | condensator | 40 |  | 2 | Condensator: ceramic; MLCC; 2,2nF; 50V; X7R; ±10%; SMD; 0805 | TME România | 0.1485 | 5.94
64 | 4.7nF | (LINK) (https://www.tme.eu/ro/details/cl21b472kbannnc/condensatoare-mlcc-smd-0805/samsung/) | CL21B472KBANNNC | CL21B472KBANNNC | SAMSUNG | condensator | 40 |  | 0 | Condensator MLCC, SMD, 0805, 4.7nF, ±5%, 50V, X7R | TME România | 0.08943 | 3.5772
65 | 5.6nF | (LINK) (https://www.tme.eu/ro/details/cl21b562kbannnc/condensatoare-mlcc-smd-0805/samsung/) | CL21B562KBANNNC | CL21B562KBANNNC | SAMSUNG | condensator | 40 |  | 0 | Condensator MLCC, SMD, 0805, 5.6nF, ±5%, 50V, X7R | TME România | 0.04517 | 1.8068
66 | 10nF | (LINK) (https://www.tme.eu/ro/details/cl21b103kbannnd/condensatoare-mlcc-smd-0805/samsung/) | CL21B103KBANNND | CL21B103KBANNND | SAMSUNG | condensator | 40 |  | 0 | Condensator MLCC, SMD, 0805, 10nF, ±5%, 50V, X7R | TME România | 0.06093 | 2.4372
67 | 22nF | (LINK) (http://www.tme.eu/ro/details/cl21b223kcfnnne/condensatoare-mlcc-smd-0805/samsung/) | CL21B223KBANNNC | CL21B223KBANNNC | SAMSUNG | condensator | 40 |  | 0 | Condensator: ceramic; MLCC; 22nF; 100V; X7R; ±10%; SMD; 0805 | TME România | 0.13823 | 5.5292
68 | 33nF | (LINK) (https://www.tme.eu/ro/details/vj0805y333kxacw1bc/condensatoare-mlcc-smd-0805/vishay/) | VJ0805Y333KXACW1BC | VJ0805Y333KXACW1BC | VISHAY | condensator | 40 |  | 0 | Condensator: ceramic; MLCC; 33nF; 50V; X7R; ±10%; SMD; 0805 | TME România | 0.05417 | 2.1668
69 | 100nF | (LINK) (https://www.tme.eu/ro/details/cl21b104kbcnnnc/condensatoare-mlcc-smd/samsung/) | CL21B104KBCNNNC | CL21B104KBCNNNC | SAMSUNG | condensator | 40 |  | 0 | ceramic; MLCC; 100nF; 50V; X7R; ±10%; SMD; 0805 | TME România | 0.3759 | 15.036
70 | 220nF | (LINK) (http://www.tme.eu/ro/details/cl21b224kafnnne/condensatoare-mlcc-smd-0805/samsung/) | CL21B224KAFNNNE | CL21B224KAFNNNE | SAMSUNG | condensator | 40 |  | 0 | Condensator: ceramic; MLCC; 220nF; 25V; X7R; ±10%; SMD; 0805 | TME România | 0.10247 | 4.0988
71 | 330nF | (LINK) (https://www.tme.eu/ro/details/grm219r71h334ka88d/condensatoare-mlcc-smd-0805/murata/) | GRM219R71H334KA88D | GRM219R71H334KA88D | MURATA | condensator | 30 |  | 0 | Condensator: ceramic; MLCC; 330nF; 50V; X7R; ±10%; SMD; 0805 | TME România | 0.5972 | 17.916
72 | 470nF | (LINK) (https://www.tme.eu/ro/details/cc0805mry5v8474/condensatoare-mlcc-smd-0805/yageo/cc0805mry5v8bb474/) | CC0805MRY5V8474 | CC0805MRY5V8BB474 | YAGEO | condensator | 30 |  | 0 | Condensator: ceramic; MLCC; 470nF; 50V; Y5V; -20÷+80%; SMD; 0805 | TME România | 0.0758 | 2.274
73 | 1uF | (LINK) (https://www.tme.eu/ro/details/cl21b105kbfnnng/condensatoare-mlcc-smd-0805/samsung/) | CL21B105KBFNNNG | CL21B105KBFNNNG | SAMSUNG | condensator | 20 |  | 0 | Condensator: ceramic; MLCC; 1uF; 50V; X7R; ±20%; SMD; 0805 | TME România | 0.25253 | 5.0506
74 | 2.2uF | (LINK) (https://www.tme.eu/ro/details/grm21br61h225ka73l/condensatoare-mlcc-smd-0805/murata/) | GRM21BR61H225KA73L | GRM21BR61H225KA73L | MURATA | condensator | 20 |  | 0 | Condensator: ceramic; MLCC; 2,2uF; 25V; X5R; ±10%; SMD; 0805 | TME România | 0.4486 | 8.972
75 | 4.7uF | (LINK) (https://www.tme.eu/ro/details/cl21a475kaqnnng/condensatoare-mlcc-smd-0805/samsung/) | CL21A475KAQNNNG | CL21A475KAQNNNG | SAMSUNG | condensator | 20 |  | 0 | ceramic; MLCC; 4,7uF; 25V; X5R; ±10%; SMD; 0805 | TME România | 0.25373 | 5.0746
76 | 10uF | (LINK) (https://www.tme.eu/ro/details/eee1ha100sp/condensatoare-electrolitice-smd/panasonic/) | EEE1HA100SP | EEE1HA100SP | PANASONIC | condensator | 16 |  | 0 | Condensator: electrolitic; SMD; 10uF; 50V | TME România | 0.2284 | 3.6544
 | TOTAL - Componente pasive (condensatoare) |  |  |  |  |  |  |  |  | FARA TVA = | 98.4844 | CU TVA= | 122.120656
77 | 4148 | (LINK) (http://www.tme.eu/ro/details/1n4148-0805/diode-universale-smd/dc-components/cd4148ws0805c/) | 1N4148-0805 | CD4148WS(0805C) | DC Components | diodă pn | 50 |  | 4 | Diodă comutație, SMD, 0805, 300mA, 100V | TME România | 0.04555 | 2.2775
78 | LED | (LINK) (https://www.tme.eu/ro/details/of-smd2012b/diode-led-smd-colorate/optoflash/) | OF-SMD2012B | OF-SMD2012B | OPTOFLASH | LED | 15 |  | 2 | LED albastru, SMD, 0805, 150-200mcd, 476nm, 120° | TME România | 0.1264 | 1.896
79 | 2.7V | (LINK) (https://www.tme.eu/ro/details/bzx84-c2v7.215/diode-zener-smd/nexperia/bzx84-c2v7-215/) | BZX84C2V7 | BZX84-C2V7LT1G | ON Semiconductor | diodă Zener | 0 |  | 0 | Diodă Zener, SMD, SOT23, 2,7V, ±5%, 0.25W | TME România | 0.05732 | 0
80 | 5.1V | (LINK) (https://www.tme.eu/ro/details/bzx84-c5v1.215/diode-zener-smd/nexperia/) | BZX84C5V1 | BZX84-C5V1 | NEXPERIA | diodă Zener | 10 |  | 0 | Diodă Zener, SMD, SOT23, 5,1V, ±5%, 0.3W | TME România | 0.06245 | 0.6245
81 | 5.6V | (LINK) (https://www.tme.eu/ro/details/bzx84b5v6-dio/diode-zener-smd/diotec-semiconductor/bzx84b5v6/) | BZX84B5V6 | BZX84B5V6 | DIOTEC SEMICONDUCTOR | diodă Zener | 10 |  | 0 | Diodă Zener, SMD, SOT23, 5,6V, ±5%, 0.3W | TME România | 0.0839 | 0.839
82 | 6.2V | (LINK) (https://www.tme.eu/ro/details/bzx84-c6v2.215/diode-zener-smd/nexperia/) | BZX84C6V2 | BZX84-C6V2 | NEXPERIA | diodă Zener | 0 |  | 0 | Diodă Zener, SMD, SOT23, 6.2V, ±5%, 0.3W | TME România | 0.06618 | 0
83 | 6.8V | (LINK) (https://www.tme.eu/ro/details/bzx84-c6v8.215/diode-zener-smd/nexperia/) | BZX84C6V8 | BZX84-C6V8 | NEXPERIA | diodă Zener | 0 |  | 0 | Diodă Zener, SMD, SOT23, 6.8V, ±5%, 0.3W | TME România | 0.05686 | 0
84 | 8.2V | (LINK) (https://www.tme.eu/ro/details/bzx84-c8v2.215/diode-zener-smd/nexperia/) | BZX84C8V2 | BZX84-C8V2 | NEXPERIA | diodă Zener | 0 |  | 0 | Diodă Zener, SMD, SOT23, 8.2V, ±5%, 0.3W | TME România | 0.05686 | 0
85 | 10V | (LINK) (https://www.tme.eu/ro/details/bzx84-c10.215/diode-zener-smd/nexperia/) | BZX84C10 | BZX84-C10 | NEXPERIA | diodă Zener | 0 |  | 0 | Diodă Zener, SMD, SOT23, 10V, ±5%, 0.3W | TME România | 0.05686 | 0
86 | PNP | (LINK) (http://www.tme.eu/ro/details/bc856b-dio/tranzistori-smd-pnp/diotec-semiconductor/bc856b/) | BC856B | BC856B | DIOTEC | tranzistor bipolar | 100 |  | 3 | Tranzistor bipolar PNP, SMD, SOT23, 80V, 100mA | TME România | 0.04055 | 4.055
87 | NPN | (LINK) (https://www.tme.eu/ro/details/bc846b-dio/tranzistori-smd-npn/diotec-semiconductor/bc846b/) | BC846B | BC846B | DIOTEC | tranzistor bipolar | 100 |  | 4 | Tranzistor bipolar NPN, SMD, SOT23, 65V, 100mA | TME România | 0.03379 | 3.379
89 | N-JFET | (LINK) (http://www.tme.eu/ro/details/mmbfj309lt1g/tranzistori-canal-n-smd/on-semiconductor/) | MMBFJ309LT1G | MMBFJ309LT1G | ON Semiconductor | tranzistor NJFET | 50 |  | 0 | Tranzistor N-JFET, SMD, SOT23, 25V, 30mA | TME România | 0.8063 | 40.315
90 | P-JFET | (LINK) (http://www.tme.eu/ro/details/mmbfj177lt1g/tranzistori-canal-p-smd/on-semiconductor/) | MMBFJ177LT1G | MMBFJ177LT1G | ON Semiconductor | tranzistor PJFET | 10 |  | 0 | Tranzistor P-JFET, SMD, SOT23, 30V, 20mA | TME România | 0.8808 | 8.808
91 | NPN | (LINK) (http://www.tme.eu/ro/details/bc817-25-dio/tranzistori-smd-npn/diotec-semiconductor/bc817-25/) | BC817-25-DIO | BC817-25-DIO | NXP | tranzistor bipolar | 10 |  | 0 | Tranzistor bipolar NPN, SMD, SOT23, 45V, 800mA | TME România | 0.0494 | 0.494
93 | PNP | (LINK) (http://www.tme.eu/ro/details/bc807-25-dio/tranzistori-smd-pnp/diotec-semiconductor/bc807-25/) | BC807-25-DIO | BC807-25-DIO | NXP | tranzistor bipolar | 20 |  | 0 | Tranzistor bipolar PNP, SMD, SOT23, 45V, 800mA | TME România | 0.05406 | 1.0812
94 | NPN | (LINK) (http://www.tme.eu/ro/details/mjd31cg/tranzistori-smd-npn/on-semiconductor/) | MJD31CG | MJD31CG | ON Semiconductor | tranzistor bipolar | 0 |  | 0 | Tranzistor bipolar NPN, SMD, DPACK, 100V, 3A, 15W | TME România | 0.7037 | 0
96 | PNP | (LINK) (http://www.tme.eu/ro/details/mjd32cg/tranzistori-smd-pnp/on-semiconductor/) | MJD32CG | MJD32CG | ON Semiconductor | tranzistor bipolar | 0 |  | 0 | Tranzistor bipolar PNP, SMD, DPACK, 100V, 3A, 15W | TME România | 0.783 | 0
97 | Nmos | (LINK) (https://www.tme.eu/ro/details/irfr120ntrpbf/tranzistori-canal-n-smd/infineon-technologies/) | IRFR120NTRPBF | IRFR120NTRPBF | Infineon | tranzistor NMOS | 0 |  | 0 | Tranzistor N-MOSFET, SMD, DPAK, 100V, 9.1A, 20V, 39W | TME România | 1.03 | 0
 | TOTAL - Componente semiconductoare (tranzistoare bipolare şi cu efect de câmp, diode, LED, etc.) |  |  |  |  |  |  |  |  | FARA TVA = | 91.0692 | CU TVA= | 112.925808
98 | Conn2p | (LINK) (http://www.tme.eu/ro/details/zl301-40p/pini-cu-benzi-si-soclu/ninigi/) | ZL301-40P | ZL301-40P | NINIGI | Sir pini, pas 2,54mm, SMD | 0 |  | 0 | Sir pini, pas 2,54mm, SMD, tip tata, bareta de 40 pini | TME România | 2.3027 | 0
99 | FUSE | (LINK) (http://www.tme.eu/ro/details/3413.0116.11/sigurante-smd-1206-ultrarapide/schurter/) | 3413.0116.11 | 3413.0116.11 | SCHURTER | sigu-ranță | 0 |  | 0 | Siguranță sticlă, SMD, 1206, 1.25A, 48mΩ | TME România | 0 | 0
 | Total - Conectică, sigurante fuzibile, etc. |  |  |  |  |  |  |  |  | FARA TVA = | 0 | CU TVA= | 0
 | Total general |  |  |  |  |  |  |  |  | FARA TVA = | 479.3852 | CU TVA= | 570.468388
